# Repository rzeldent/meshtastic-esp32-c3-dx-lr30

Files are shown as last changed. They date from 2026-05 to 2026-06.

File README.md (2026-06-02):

# Meshtastic ESP32-C3 + DX-LR30

DIY Meshtastic node using an ESP32-C3 supermini and an SX1262-based DX-LR30 LoRa module.

This repository includes:
- PCB schematic files
- PCB layout and EasyEDA board files
- Generated Gerber files for fabrication
- Modified Meshtastic firmware support for the Heltec ESP32-C3 variant with custom pin mappings

The design is intended to provide a compact custom Meshtastic node with a small OLED display and LoRa radio.

## Hardware

### Target modules
- DX-LR30 LoRa module (SX1262)
- ESP32-C3 supermini board
- Standard I2C OLED module (SSD1306-compatible)

### Recommended sourcing
- DX-LR30 module: https://nl.aliexpress.com/item/1005009833029680.html
- ESP32-C3 supermini board: https://nl.aliexpress.com/item/1005006056663228.html
- I2C OLED module: https://nl.aliexpress.com/item/1005007551771400.html

> Important: Do not use 433 MHz DX-LR30 variants for Meshtastic if you intend to run 868 MHz firmware. This design targets 868 MHz operation (European Union frequencies).

## What is included

- `schematic/` — EasyEDA schematic files for the ESP32-C3 and DX-LR30 connections
- `pcb/` — EasyEDA PCB design files and layout
- Gerber export files for PCB fabrication
- Custom Meshtastic firmware changes for the Heltec ESP32-C3 board variant

## Firmware adaptation

This project is based on the Heltec ESP32-C3 board configuration. The firmware changes update pin definitions to match the DX-LR30 module and the custom board wiring.

To build the firmware:
1. Install PlatformIO.
2. Copy the modified files from this repository into `meshtastic/variants/esp32c3/heltec_esp32c3/`.
3. Open the Meshtastic project in PlatformIO.
4. Run the build command for the Heltec ESP32-C3 environment.
   - Example: `pio run -e heltec_esp32c3`
5. Upload to the ESP32-C3 using `pio run -e heltec_esp32c3 -t upload`.

## Pin mappings

### DX-LR30 wiring

| Board pin | ESP32-C3 GPIO | DX-LR30 signal | Function |
|---|---|---|---|
| `SS` | `GPIO8` | `NSS` / `CS` | SPI chip select |
| `SCK` | `GPIO9` | `SCK` | SPI clock |
| `MOSI` | `GPIO7` | `MOSI` | SPI MOSI |
| `MISO` | `GPIO6` | `MISO` | SPI MISO |
| `GPIO5` | `GPIO5` | `RESET` | Module reset |
| `GPIO3` | `GPIO3` | `DIO1` | LoRa interrupt / status |
| `GPIO4` | `GPIO4` | `BUSY` | LoRa busy |
| `3V3` | — | `VCC` | Power supply |
| `GND` | — | `GND` | Ground |

- `DIO0` and `DIO2` are not connected in this variant (`RADIOLIB_NC`).
- `GPIO8` is shared with the board blue LED, so radio activity may also light the LED and slightly increase power consumption.

### OLED wiring

| Board pin | ESP32-C3 GPIO | OLED signal | Function |
|---|---|---|---|
| `SDA` | `GPIO20` | `SDA` | I2C data |
| `SCL` | `GPIO21` | `SCL` | I2C clock |
| `3V3` | — | `VCC` | Power supply |
| `GND` | — | `GND` | Ground |

## Usage

- After flashing, pair the node using the Meshtastic mobile app.
- Use the app to configure region, frequency, and device settings.
- Verify the board is powered by 3.3V and that the LoRa antenna is properly connected.

## Known issues and notes

- MOSI and SCK are currently swapped in the implementation and should be fixed in a future revision.
- `GPIO8` is also connected to the blue LED, which increases idle power use.
- The red board LED cannot be turned off in this design, so it consumes some power continuously.
- An ESP32-S3 board with PSRAM is a better choice for a future version, because it supports message storage and forwarding more easily.
- I2C is remapped to `GPIO20` / `GPIO21`; the original ESP32 mapping was `GPIO1` / `GPIO0`.
- Unused GPIOs are available for additional peripherals such as a buzzer or extra I/O.

## Final result

The finished build is a compact Meshtastic node with a small OLED and DX-LR30 LoRa radio.

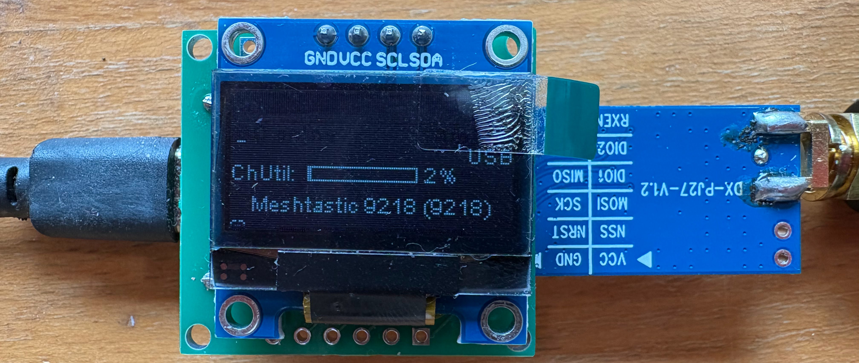
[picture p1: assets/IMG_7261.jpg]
Project - OLED side


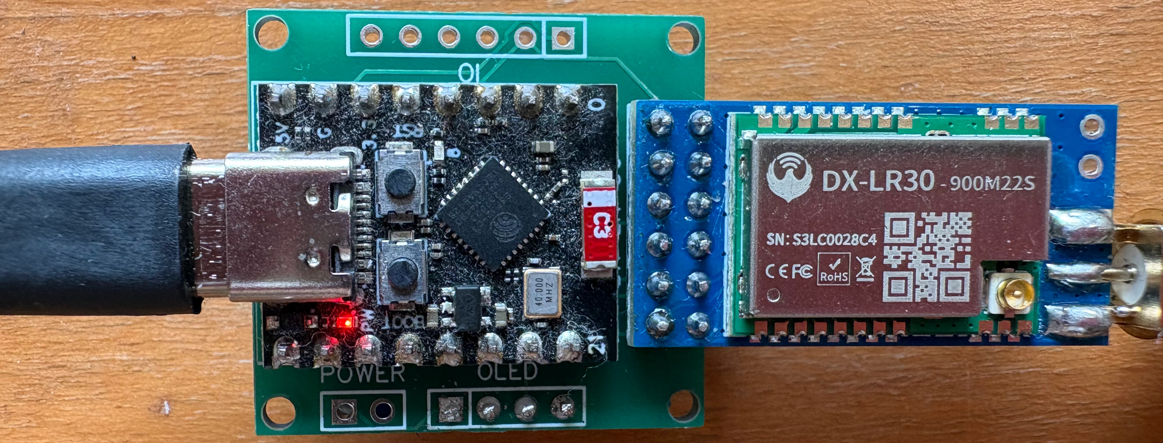
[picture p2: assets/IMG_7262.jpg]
Project - ESP/LoRa side


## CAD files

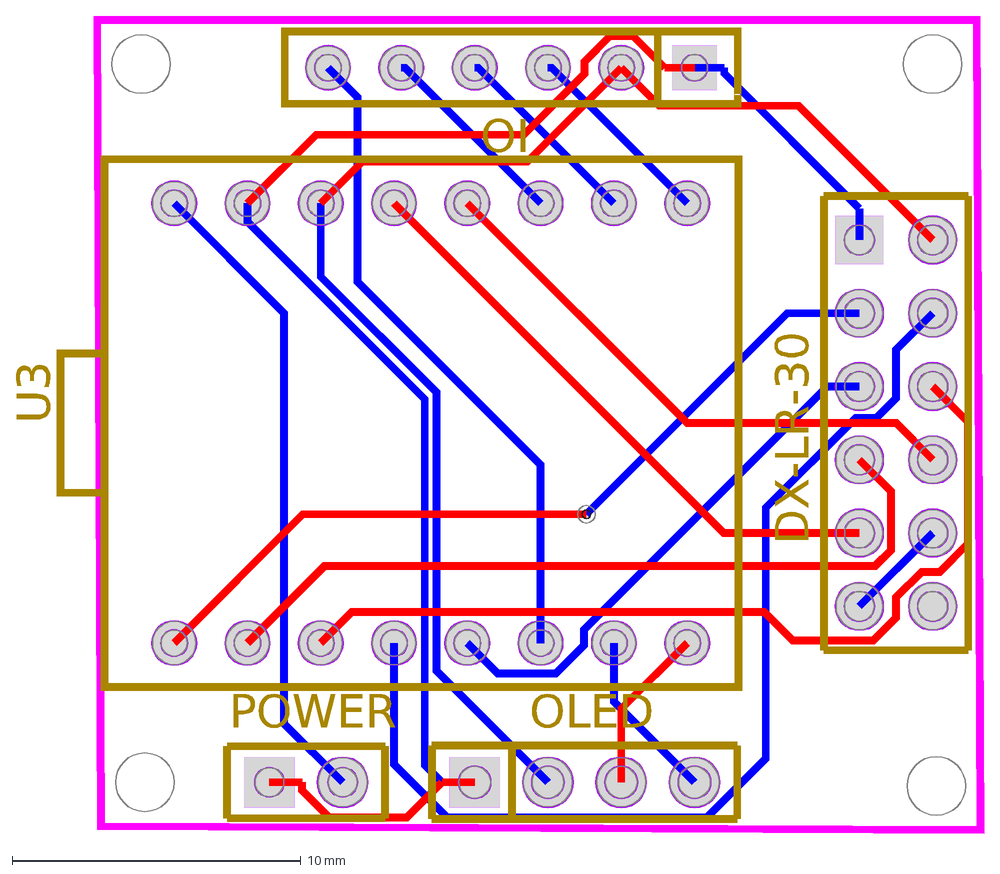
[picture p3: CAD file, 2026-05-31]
PCB_Meshtastic-ESP32-S3-mini-+-DX-LR-30_2026-05-31.dxf
IO
U3
DX-LR-30
OLED
POWER

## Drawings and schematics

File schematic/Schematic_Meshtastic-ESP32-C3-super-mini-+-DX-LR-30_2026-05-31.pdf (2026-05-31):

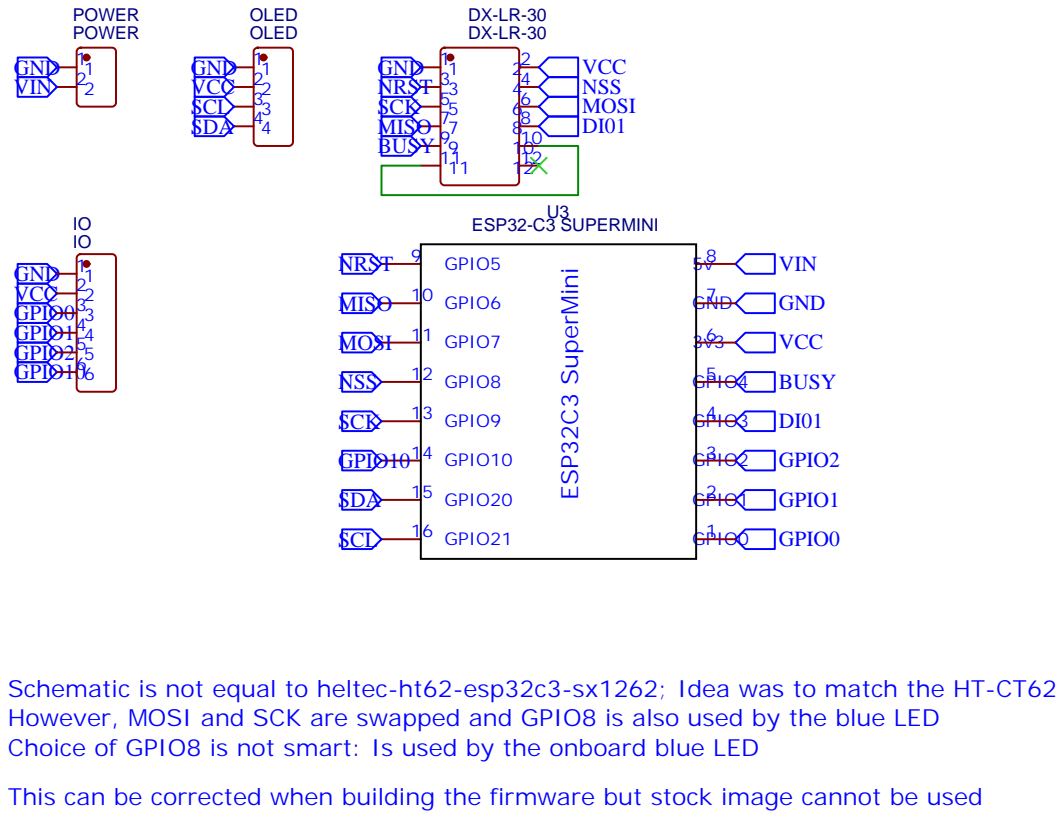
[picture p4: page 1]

Schematic is not equal to heltec-ht62-esp32c3-sx1262; Idea was to match the HT-CT62
However, MOSI and SCK are swapped and GPIO8 is also used by the blue LED
Choice of GPIO8 is not smart: Is used by the onboard blue LED
This can be corrected when building the firmware but stock image cannot be used

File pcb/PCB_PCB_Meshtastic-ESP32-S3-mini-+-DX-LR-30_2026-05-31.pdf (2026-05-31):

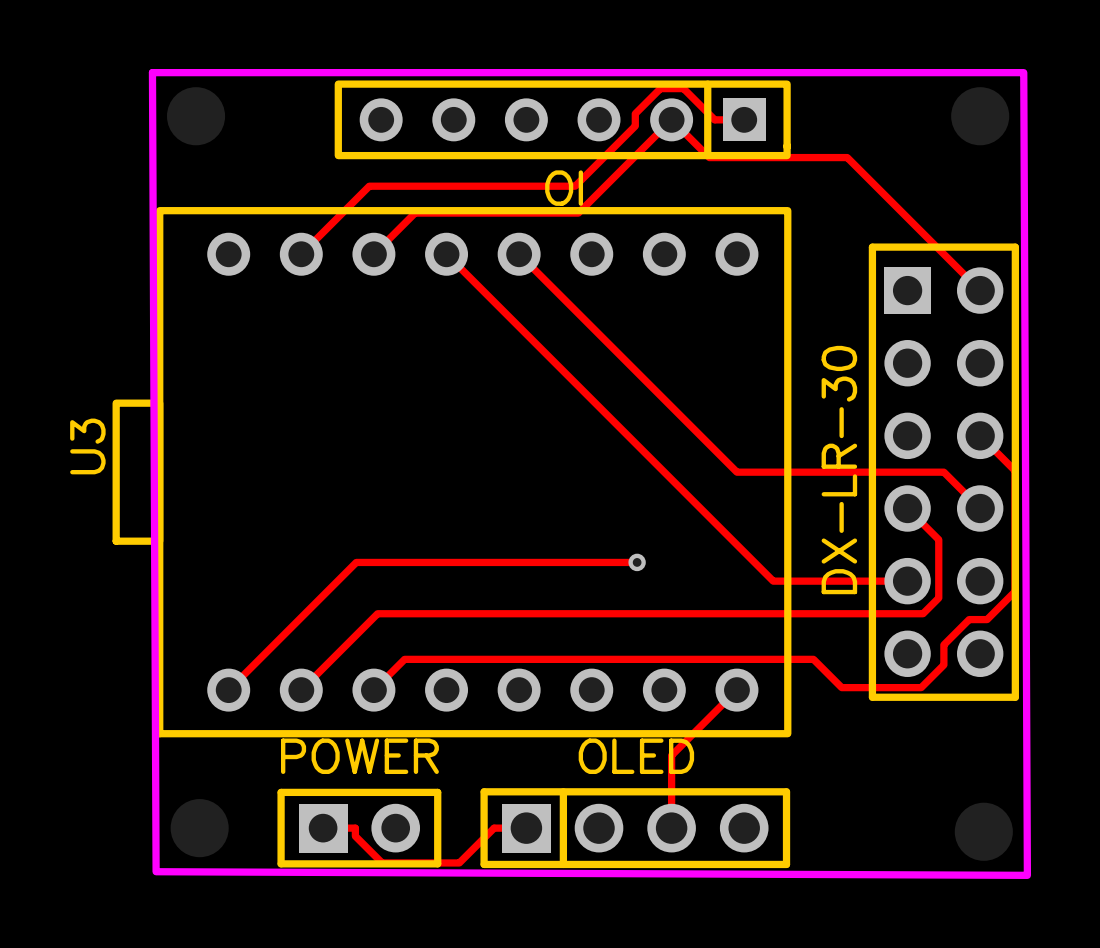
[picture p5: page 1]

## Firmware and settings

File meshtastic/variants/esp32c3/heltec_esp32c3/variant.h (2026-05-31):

// LED pin on HT-DEV-ESP_V2 and HT-DEV-ESP_V3
// https://resource.heltec.cn/download/HT-CT62/HT-CT62_Reference_Design.pdf
// https://resource.heltec.cn/download/HT-DEV-ESP/HT-DEV-ESP_V3_Sch.pdf

#define BUTTON_PIN 2
#define BUTTON_NEED_PULLUP

#define HAS_SCREEN 1

#define HAS_GPS 0
#undef GPS_RX_PIN
#undef GPS_TX_PIN

#define USE_SSD1306
#define I2C_SDA SDA
#define I2C_SCL SCL

#define USE_SX1262
#define LORA_SCK SCK
#define LORA_MISO MISO
#define LORA_MOSI MOSI
#define LORA_CS SS
#define LORA_DIO0 RADIOLIB_NC
#define LORA_RESET 5
#define LORA_DIO1 3
#define LORA_DIO2 RADIOLIB_NC
#define LORA_BUSY 4

#define SX126X_CS LORA_CS
#define SX126X_DIO1 LORA_DIO1
#define SX126X_BUSY LORA_BUSY
#define SX126X_RESET LORA_RESET
#define SX126X_DIO2_AS_RF_SWITCH
#define SX126X_DIO3_TCXO_VOLTAGE 1.8

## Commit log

2026-05-31 Refactor code structure for improved readability and maintainability
    [PCB_Meshtastic-ESP32-S3-mini-+-DX-LR-30_2026-05-31.dxf, Sheet_1_2026-05-31.schdoc]
2026-05-31 Update README.md with additional OLED pin mapping and improvements
2026-05-31 Add note to check for 2x8 pin configuration on ESP32-C3 supermini board
